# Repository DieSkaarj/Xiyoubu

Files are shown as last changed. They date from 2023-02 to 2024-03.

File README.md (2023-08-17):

# Xiyoubu - Mega Drive Does What Genesis-done.

Xiyoubu is a hardware console mod for the Mega Drive/Genesis that targets ****MH-ATtiny88**** boards. It lets the Mega Drive change between 50Hz and 60Hz for video output (through scart) and enables language options for compatible software on the board. It also details a method for decreasing the power intake of the unit by way of a USB-C power port.

Xiyoubu will load the last saved profile on console power on.

Default config...

#### Controller
Menu I: **(START + A + C + [...])**
- **B**  - In-Game Reset
- **D-PAD**
- - **RIGHT** - Region Cycle Forward (see: fig. 1)
- - **LEFT** - Region Cycle Backward (see: fig. 1)
- - **UP** - Save current region to EEPROM
- - **DOWN** -  Check Overclocking (see: fig. 2)

Menu II: **(START + B + [...])**
- **D-PAD**
- - **UP** - Overclock (+) (Step up MAJ)
- - **RIGHT** - Overclock (+) (Step up MIN)
- - **DOWN** - Overclock (-) (Step down MAJ)
- - **LEFT** - Overclock (-) (Step down MIN)

#### Console
- Hold **RESET** to cycle regions
- **Tap once** to reset
- **Tap twice** to save region
- **Tap thrice** to enable/disable Xiyoubu controller handling (this option is saved and will be remembered after poweroff.)

*Fig. 1*
 |Region|LED| 
|---|---|
|USA|Blue| 
|PAL|Red|
|JAP|Magenta|

*Fig. 2*
|Mhz|Color|
|---|---|
|7+|Green|
|8+|Yellow|
|9+|Red|
|10+|Magenta|
|11+|Blue|
|12+|White|

### Status
- v1.04
- - Tested on: MD2 VA1 PAL

### Features
- [X] Controller Region Cycling
- [X] Physical Region Cycling
- [X] Restore Region On Power On
- [X] In-Game Reset
- [X] Overclock
- [ ] Installation Walkthrough
- [X] Use Guide

### Other Mega Drive related projects from the Author
* Ko-fi blog discussing the development of Xiyoubu: https://ko-fi.com/dieskaarj
* BlastEd - Mega Drive/Genesis Art Tool: https://dieskaarj.itch.io/blasted

### Thank you for your hard work, research and resources
* **SukkoPera:** https://github.com/SukkoPera/MegaDrivePlusPlus
* **TurBoss:** https://github.com/TurBoss/MegaDrivePlusPlus/tree/overclock
* **Smudger D:** https://stompville.co.uk/?p=853
* **SpenceKonde:** https://github.com/SpenceKonde/ATTinyCore
* **Raspberryfield:** https://www.raspberryfield.life/2019/03/25/sega-mega-drive-genesis-6-button-xyz-controller/
* **Charles MacDonald:** https://gendev.spritesmind.net/forum/viewtopic.php?t=1262
* **Liam Riordan:** https://www.analog.com/media/en/technical-documentation/application-notes/AN-1070.pdf
* **Atmel:** http://ww1.microchip.com/downloads/en/DeviceDoc/atmel-9157-automotive-microcontrollers-attiny88_datasheet.pdf
* **Analog Devices:** https://www.analog.com/media/en/technical-documentation/data-sheets/ad9833.pdf

### License
Xiyoubu (software) is Copyright © 2023 by David 'Erosion' Oberlin.

This program is free software: you can redistribute it and/or modify it under the terms of the GNU General Public License as published by the Free Software Foundation, either version 3 of the License, or (at your discretion) a later version.

This program is distributed in the hope that it will be useful, but WITHOUT ANY WARRANTY; without even the implied warranty of MERCHANTABILITY or FITNESS FOR A PARTICULAR PURPOSE. See the GNU General Public License for more details.

You should have received a copy of the GNU General Public License along with this program. If not, see http://www.gnu.org/licenses/.

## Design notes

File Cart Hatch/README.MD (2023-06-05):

The STL is a replacement patch for the MD cart slot. It is modelled after the Mega Drives released on the asian market and you will have to alter a EU/US case to accommodate.

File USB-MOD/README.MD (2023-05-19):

****MD1****

Remember to adjust for printer tolerances. I used .01 for both ABS and PLA with the front and .005 on the back. Also note that, unless you are lighter than a photon in a star, it is advised to use glue to hold this in.

****MD2 & MCD2****
***Scale the nut to be slightly larger.***

Also, cut the bridge at the end of the bolt to accommodate a board, this is to act as a clip.

I added .008 on the bolt-socket, and .2 on the nut and had good results.

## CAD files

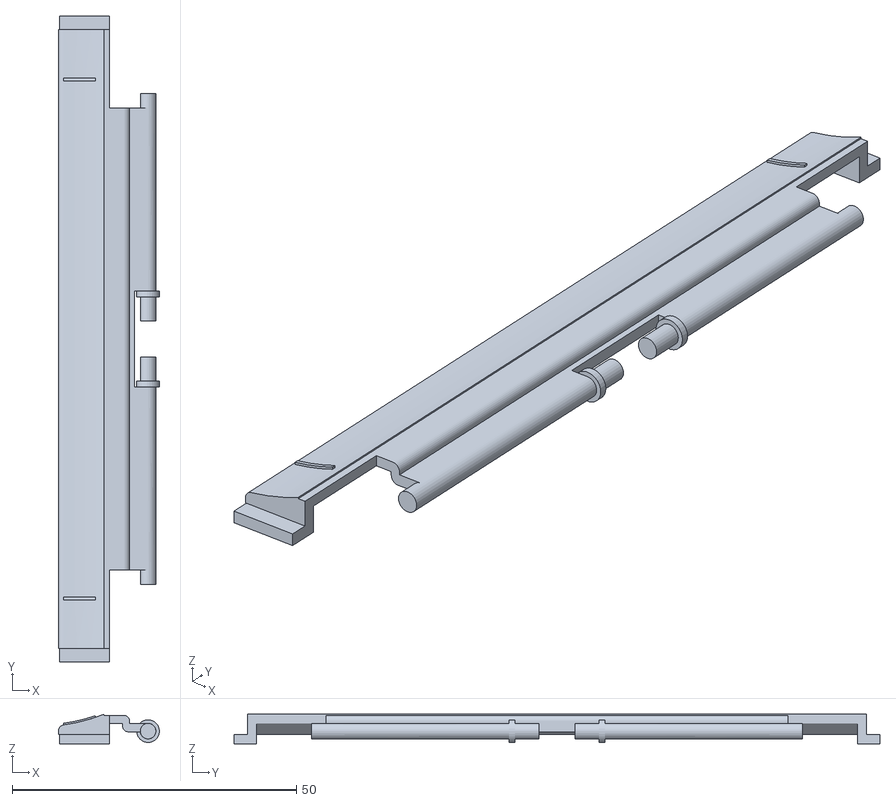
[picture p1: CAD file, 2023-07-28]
Cart Hatch/md_hatch.stl
17.8 x 113.6 x 5.20

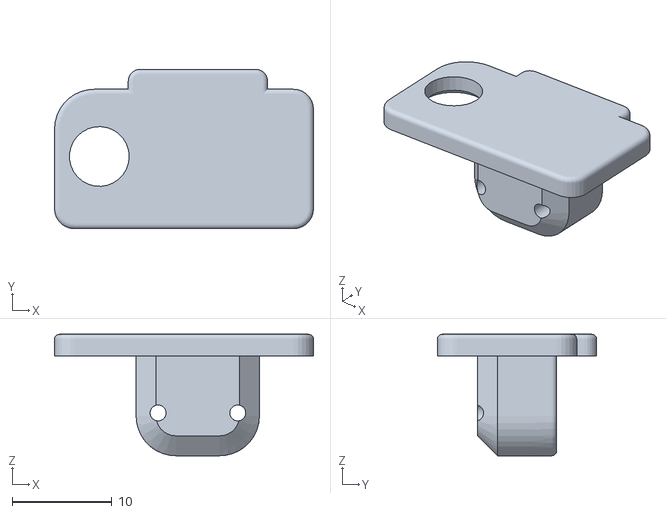
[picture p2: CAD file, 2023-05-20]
USB-MOD/MD1-Back.stl
26.0 x 16.0 x 12.2

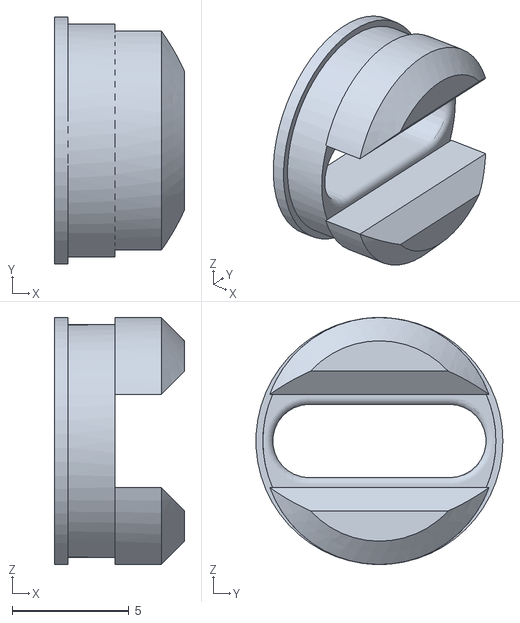
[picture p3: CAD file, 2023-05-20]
USB-MOD/MD1-Front.stl
5.60 x 10.6 x 10.6

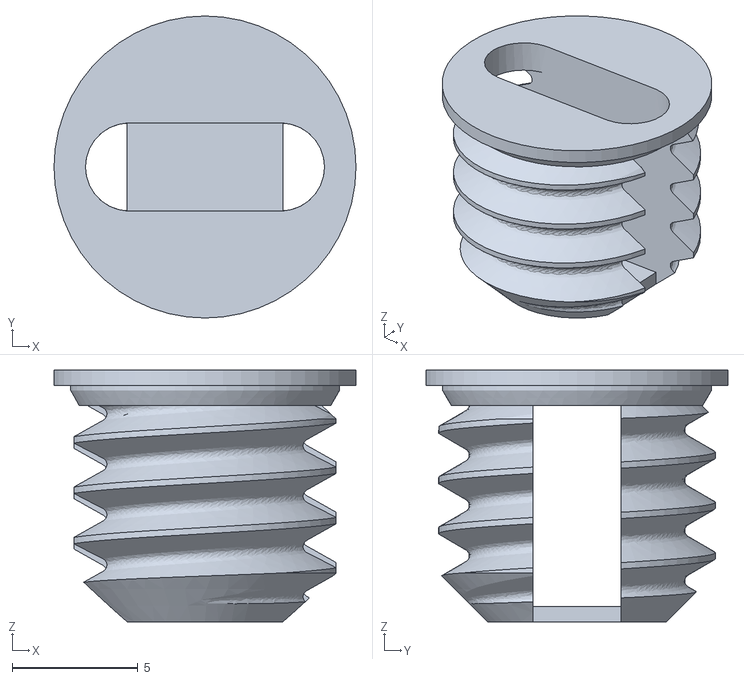
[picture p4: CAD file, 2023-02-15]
USB-MOD/bolt-socket.stl
12.0 x 12.0 x 10.00

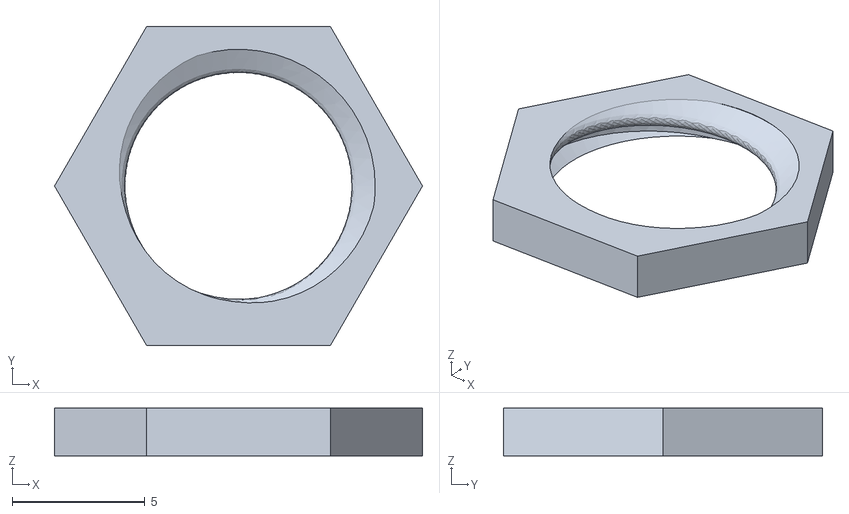
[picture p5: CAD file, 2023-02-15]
USB-MOD/nut.stl
13.9 x 12.0 x 1.80

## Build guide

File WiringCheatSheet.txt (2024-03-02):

                                Davids' all in one Mega Drive Mod wiring guide

### REGION
------------------------------------------------------------------------------------------------------------------
 Colour * Port Ref.| Connection                     Model                  Connection    | Port Ref.* Colour           
        *          |                              +-------+                              |          *
        *          |               +--------------|  USB  |--------------+               |          *
        *          |               |              +-------+              |               |          *
        *   P_A2   |               | [ ] 15                        14[*] | Halt (MD CPU) |   P_B7   * Blue
Red     *   P_A3   | LED R         | [*] 16                    SCK 13[*] | Clock (AD9833)|   P_B5   * Yellow
Green   *   P_A0   | LED G         | [*] A6                   MISO 12[ ] |               |   P_B4   * 
Blue    *   P_A1   | LED B         | [*] A7                   MOSI 11[*] | Data  (AD9833)|   P_B3   * Green
White   *   P_C0   | Reset Write   | [*] A0                     SS 10[*]~| FSYNC (AD9833)|   P_B2   * Grey
Black   *   P_C1   | Reset Read    | [*] A1                         9[ ]~|               |   P_B1   * 
Grey    *   P_C2   | JP1/2 (JP/EN) | [*] A2                         8[ ] |               |   P_B0   * 
Grey    *   P_C3   | JP3/4 (50/60) | [*] A3                         7[*] | Pad Right     |   P_D7   * Yellow
Grey    *   P_C4   | Bios Pin38    | [*] A4/SDA                     6[*] | Pad Left      |   P_D6   * Orange
Grey    *   P_C5   | Bios Pin39    | [*] A5/SCL                     5[*] | Pad Down      |   P_D5   * Red
        *   P_C7   |               | [ ] 25                         4[*] | Pad Up        |   P_D4   * Brown
        *          |               | [ ] RST                   INT1/3[*] | Pad (Signal)  |   P_D3   * Grey
        *   P_D0   |               | [ ] 0                         5V[*] | 5V            |          * Red
White   *   P_D1   | Pad Start/C   | [*] 1      VCC  MOSI GND     GND[*] | GND           |          * White
Blue    *   P_D2   | Pad A/B       | [*] 2/INT0 [ ]  [ ]  [ ]     VIN[ ] |               |          *
        *          |               |            [ ]  [ ]  [ ]            |               |          *
        *          |               |            MISO SCK  RST            |               |          *
        *         /                +--ATtiny88---------------------------+               \          *
------------------------------------------------------------------------------------------------------------------                                                
Dia. 2: MD Board Underside * Dia. 3: Controller wire layout                      
       +-----------+       * +-----------+-----------+-----------+-----------+-----------+-----------+-----------+
       | 5 4 3 2 1 |       * |  P_D1 :1  |  P_D2 :2  |  P_D3 :3  +  P_D7 :7  +  P_D6 :6  +  P_D5 :5  +  P_D4 :4  +
       \  9 8 7 6  /       * +-----------+-----------+-----------+-----------+-----------+-----------+-----------+
         +-------+         * | 9:Start/C |  7:Signal |   6:A/B   |  4:Right  |  3:Left   |   2:Down  |   1:Up    |
                           * +-----------+-----------+-----------+-----------+-----------+-----------+-----------+
                           * |   White   |    Grey   |   Blue    |  Yellow   |  Orange   |    Red    |   Brown   |
                           *  +----------+-----------+-----------+-----------+-----------+-----------+----------+
------------------------------------------------------------------------------------------------------------------
Notes:
* 8:GND (Unused,) 5:+5V (Unused) can be used to power the MH-ATtiny88 board.

### VIDEO_CRYSTAL
------------------------------------------------------------------------------------------------------------------
AD9833  |              Connection
------------------------------------------------------------------------------------------------------------------
OUT     | --> \   PIN_6   [XTAL IN / CX1145P]
AGND    | --> \   PIN_5   [XTAL OUT / CX1145P]
FSYNC   | --> |   PIN_10  [SS 10 / MH-ATtiny88]
SCLK    | --> |   PIN_13  [SCK 13 / MH-ATtiny88]
SDATA   | --> |   PIN_11  [MOSI 11 / MH-ATtiny88]
DGND    | --> /   5V      [MD Motherboard]
VCC     | --> /   GND     [MD Motherboard]
------------------------------------------------------------------------------------------------------------------
Notes:
*  Only available on Mega Drive/Genesis 1 Models
*  Disconnect PIN_6 on the CX1145P from the main board of the Mega Drive.
*  Bridge PIN_1 to PIN 7 for PAL (GND.) Bridge PIN_12 to PIN_7 for NTSC (VCC.)

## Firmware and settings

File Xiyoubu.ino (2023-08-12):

/*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

    File: main.cpp

    Desc: Entrance

    Author: David A. Cummings (David Oberlin)
    Contact: davidandrewcummings@hotmail.co.uk

*/

#include "config.h"
#include "console.h"
#include "controller.h"
#include "chronojohn.h"
#include "pins_xiyoubu.h"

using namespace SETUP;

static const Console *MEGA_DRIVE{ nullptr };
static const Controller *PAD{ nullptr };

ISR( TIMER1_COMPA_vect )
{
  ++TICKS;
}

ISR( V_SELECT )
{
  Controller::poll( PAD,D_SELECT,D_CONTROLLER );
}

ISR( V_CONSOLE )
{
  Console::poll( MEGA_DRIVE,D_BUTTON );
}

int main()
{
  using namespace CHRONOJOHN;

  init();
  start_ticks();

  noInterrupts();

  MEGA_DRIVE = new Console( ticks() );
  PAD = new Controller( MEGA_DRIVE );

  MEGA_DRIVE->on_startup( STARTUP_TIME );

  interrupts();

  while ( true )
  {
    const milliseconds_t tocks{ millis() };

    MEGA_DRIVE->handle( tocks );
    PAD->handle( tocks );
  }

  return EXIT_SUCCESS;
}

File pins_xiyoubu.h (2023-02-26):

#ifndef _PIN_XIYOUBU_H
#define _PIN_XIYOUBU_H

#include "Arduino.h"

/*
  Pre-fixes:

  D_ - Data (Read)
  M_ - Macro
  P_ - Pin/Port
  V_ - Vector

*/
#define EXT_PIN_INTERRUPTS( v ) ( PCICR  =  v )
#define EXT_PIN_MASK_VECTS( v ) ( PCMSK1 =  v )
#define CONTROLLER_INTERRUPT( v ) ( EICRA = v )
#define CONTROLLER_INTR_MASK( v ) ( EIMSK = v )

/*
   LED pins
*/
#define P_LED PORTA
#define P_GREEN PA0
#define P_BLUE PA1
#define P_RED PA3

#define SETUP_LED(ddr,prt) ( P_LED = prt ); ( DDRA = ddr );

/*
   CPU/Overclocking pins
*/
#define P_CLOCK PORTB
#define P_FSYNC PB2 // Can be moved to another pin
#define P_SDATA PB3
#define P_SCLOCK PB5
#define P_HALT PB7

#define SETUP_CLOCK(ddr,prt) ( P_CLOCK = prt ); ( DDRB = ddr );

/*
   Console pins
*/
#define P_CONSOLE PORTC
#define P_RESET PC0
#define P_BUTTON PC1
#define P_VIDEO PC2
#define P_LANG PC3

#define D_CONSOLE PINC
#define D_BUTTON static_cast< bool >( D_CONSOLE & _BV( P_BUTTON ) )

#define V_CONSOLE PCINT1_vect
#define V_BUTTON _BV( PCINT9 )

#define ENABLE_CONSOLE _BV( PCIE1 )
#define SETUP_CONSOLE(ddr,prt) ( P_CONSOLE = prt ); ( DDRC = ddr );

/*
   Controller pins
*/
#define P_CONTROLLER PORTD
#define P_SELECT PD3

#define D_CONTROLLER PIND
#define D_SELECT static_cast< bool >( D_CONTROLLER & _BV( P_SELECT ) )

#define V_SELECT INT1_vect

#define SELECT_SIGNAL _BV( ISC10 )
#define SELECT_SIGMSK _BV( INT1 )

#define SETUP_CONTROLLER(ddr,prt) ( P_CONTROLLER = prt ); ( DDRD = ddr );

#endif//_PIN_XIYOUBU_H

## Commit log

2023-01-11 Add files via upload
    - Fixed region swapping on controller. I was experimenting with the debounce and forgot to upload it in a working state.
    - Implemented rudimentary IGR.
    [Xiyoubu.ino]
2023-01-14 Add files via upload
    On board reset and region change now functioning. Plus, more housekeeping.
    [Xiyoubu.ino]
2023-01-31 Add files via upload
    Messy but functional code. Changes that have been made are flipping both the reset and region wires plus the inclusion of a green channel for the LED.
    [Xiyoubu.ino]
2023-02-04 Add files via upload
    Changed global static objects to (global static) pointers.
    Changed local static variables to class members (RAII.)
    Expanded and renamed annul_press_counter() function to reset the timeout class member too.
    [Xiyoubu.ino]
2023-02-04 Update Xiyoubu.ino
    Removed old pin layout. Wiring Cheat Sheet contains all the necessary diagrams.
2023-02-04 Added height jig for usb mod.
    [mdii.jig.stl]
2023-02-04 Fixed timers resetting only on single tap.
2023-02-06 Changed FNC_PIN to correlate to wiring guide.
2023-02-06 Updated halt with correct pin.
2023-02-15 No longer required.
    [mdii.jig.stl]
2023-02-18 Updated Wiring Guide
2023-02-21 Tightening up timings
2023-02-22 Fixed button press conditional
2023-02-25 Added Sampler for Controller
2023-03-11 moved sample handling code to its own function
2023-03-14 “A starving camel is still bigger than a horse.”
2023-05-19 Added Mega Drive Model 1 USB solutions
    [md1jig-BodyPocket005.stl, plug.stl]
2023-05-19 Added named MD1-solutions
    [MD1-Back.stl, MD1-Front.stl]
2023-05-19 Stupid name and renaming semantics
    [md1jig-BodyPocket005.stl]
2023-05-19 Dumb name and renaming semantics
    [plug.stl]
2023-05-19 Minor adjustment
    [MD1-Back.stl]
2023-05-20 Adapted to lessen the need for glue
    [MD1-Back.stl, MD1-Front.stl]
2023-06-07 Adjusted for resin
    [md_hatch.stl]
2023-07-23 Re-adjusted to correct parameters
    [md_hatch.stl]
2023-07-28 So final it is finished.
    [md_hatch.stl]
2024-02-28 Added config for using AD9833 as video crystal.
    Added a couple of constants to setup the AD9833 as a video crystal. Setting the AV-IC to output PAL60 or NTSC50. TODO: Further details for modifying the hardware.
    (Lift/disconnect pin 6 & 7 on IC. Ground 7 and connect AD9833 OUT to Pin 6.)
2024-03-01 Fixed timers.
    Timers were being reset with a past copy of ticks (t_ticks) this gets the actual ticks from the millis() function.
2024-03-02 Update WiringCheatSheet.txt
    Added instructions for AD9833 as video crystal.
